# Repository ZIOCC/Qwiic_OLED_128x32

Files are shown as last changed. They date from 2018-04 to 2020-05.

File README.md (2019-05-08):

# Zio Qwiic OLED Display (0.91", 128x32 pixels)

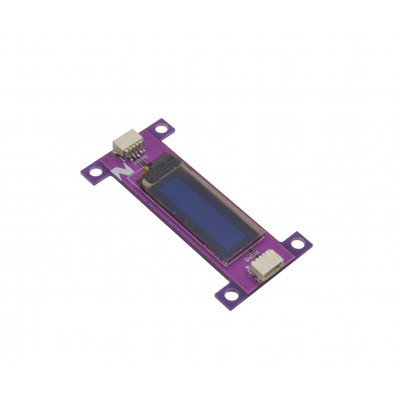
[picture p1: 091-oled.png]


> This product can be available for purchase [here](https://www.smart-prototyping.com/Zio-OLED-Display-0-91-in-128-32-Qwiic.html).

#### Description

This Zio OLED Display features a whopping 128x32 pixels in a small 0.91” (diagonal) frame. That’s 4,000 itsy-bitsy LEDs. [pause for effect]

Speed isn’t compromised however, thanks to its I2C command structure. Your firmware only needs to send the changes that it wants to make, rather than transferring information for every single pixel during each screen update.

As an OLED, it comes with all the perks of being able to emit light (unlike LCDs). No backlight layer here! Therefore, it’s thinner, consumes less power, and has higher contrast. With this size, it can display up to 3 lines of text.

The breakout board also features 4 mounting holes that can be snapped off and 2 Qwiic connectors to allow for quick and easy daisy-chaining.

> Note: As with all of the Version 1.0 Zio Qwiic boards, this board has been produced with the I2C pull-ups disconnected by default. If there's a significant length of wire between this board and your MCU, you'll need to solder closed the solder jumpers (labeled SDA, 3v3 and SCL) to connect the pull-up resistors to VCC.

#### Specification

* Communication Protocols: I2C
* IC: SSD1306
* I2C address: 0x3C
* Dimensions with Mounting  Tab: 25.1x 50.3mm
* Dimension without Mounting  Tab: 50.3x15.1mm
* Weight: 5g

#### Links

* [Adafruit GFX Library](https://github.com/adafruit/Adafruit-GFX-Library)
* [Adafruit SSD1306 Library](https://github.com/adafruit/Adafruit_SSD1306)
* [Demo Code](https://github.com/adafruit/Adafruit_SSD1306/tree/master/examples/ssd1306_128x32_i2c)
* [Eagle files](https://github.com/ZIOCC/Qwiic_OLED_128x32)

> ###### About Zio
> Zio is a new line of open sourced, compact, and grid layout boards, fully integrated for Arduino and Qwiic ecosystem. Designed ideally for wearables, robotics, small-space limitations or other on the go projects. Check out other awesome Zio products [here](https://www.smart-prototyping.com/Zio).

> All Zio products are released under the [Creative Commons Attribution, Share-Alike License](https://creativecommons.org/licenses/by-sa/4.0/), and in accordance with the principles of the [Open Source Hardware Association's OSHW Statement of Principles 1.0 and OSHW Definition 1.0](https://www.oshwa.org/definition/).

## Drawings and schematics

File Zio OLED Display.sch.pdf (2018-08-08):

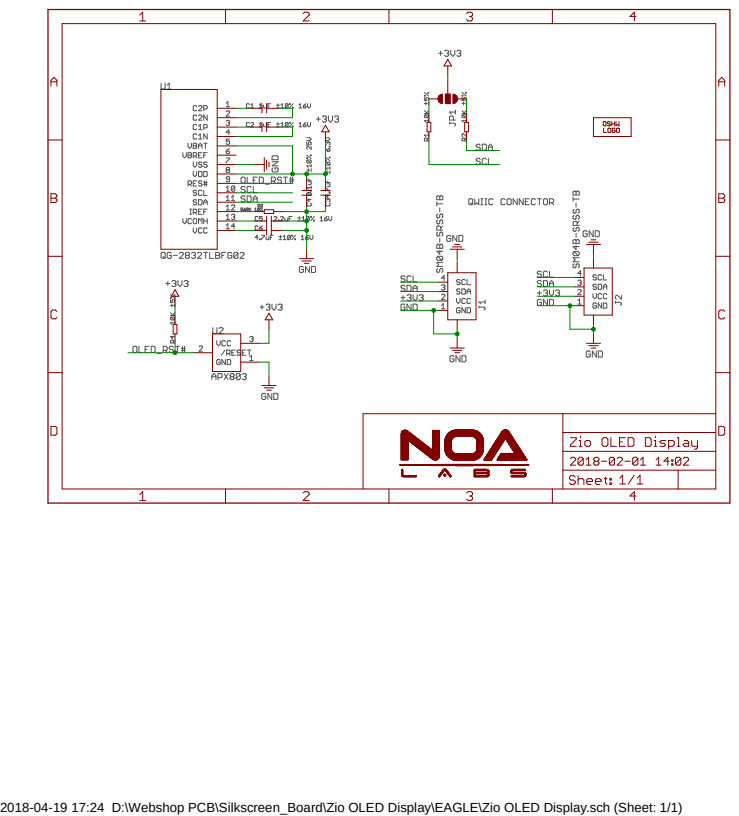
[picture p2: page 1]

2018-04-19 17:24 D:\Webshop PCB\Silkscreen_Board\Zio OLED Display\EAGLE\Zio OLED Display.sch (Sheet: 1/1)

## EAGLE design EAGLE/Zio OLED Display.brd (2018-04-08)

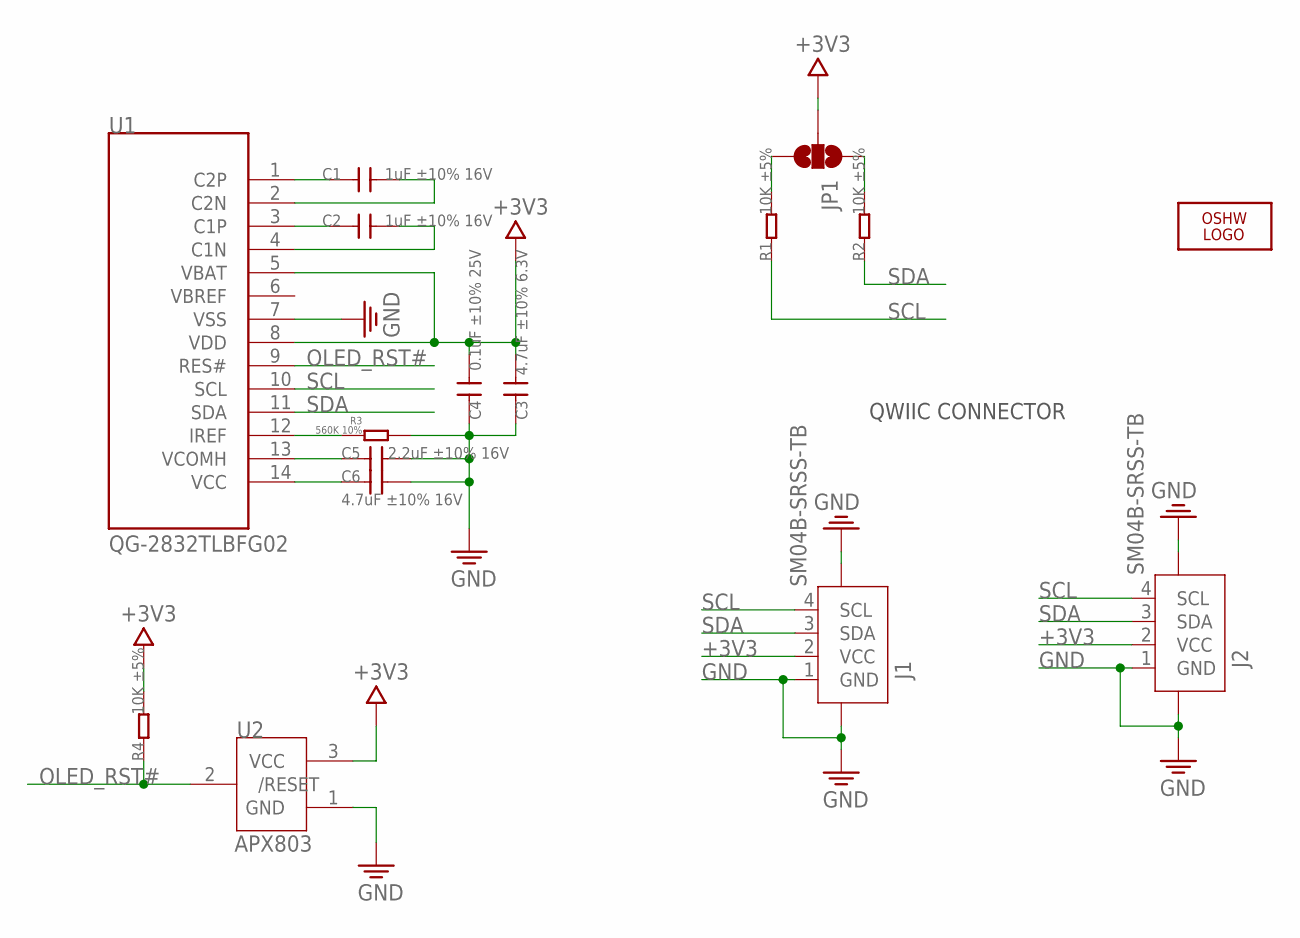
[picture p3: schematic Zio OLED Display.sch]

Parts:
C1, C2: 1uF ±10% 16V; 0603
C3: 4.7uF ±10% 6.3V; 0603
C4: 0.1uF ±10% 25V; 0603
C5: 2.2uF ±10% 16V; 0603
C6: 4.7uF ±10% 16V; 0603
J1, J2: SM04B-SRSS-TB; JST-SH-4P
JP1: JUMPER-SMT_3_2-NC_PASTE_NOCREM; SMT-JUMPER_3_2-NC_PASTE_SILK_NOCREM
LOGO1: LOGO-OSHW-6MILX0070-NT; OSHW_6X70_NOTEXT
R1, R2, R4: 10K ±5%; 0603
R3: 560K 10%; 0603
U1: QG-2832TLBFG02; OLED-12832
U2: APX803; SOT23

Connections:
+3V3: C3.1, C4.1, J1.2 (VCC), J2.2 (VCC), JP1.2, R4.2, U1.5 (VBAT), U1.8 (VDD), U2.3 (VCC)
GND: C3.2, C4.2, C5.2, C6.2, J1.1 (GND), J1.NC1 (5), J1.NC2 (6), J2.1 (GND), J2.NC1 (5), J2.NC2 (6), R3.1, U1.7 (VSS), U2.1 (GND)
unnamed: C1.2, U1.1 (C2P)
unnamed: C1.1, U1.2 (C2N)
unnamed: C2.2, U1.3 (C1P)
unnamed: C2.1, U1.4 (C1N)
unnamed: JP1.3, R1.2
unnamed: C5.1, U1.13 (VCOMH)
unnamed: C6.1, U1.14 (VCC)
unnamed: JP1.1, R2.2
unnamed: R3.2, U1.12 (IREF)
OLED_RST#: R4.1, U1.9 (RES#), U2.2 (/RESET)
SCL: J1.4 (SCL), J2.4 (SCL), R1.1, U1.10 (SCL)
SDA: J1.3 (SDA), J2.3 (SDA), R2.1, U1.11 (SDA)

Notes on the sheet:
QWIIC CONNECTOR

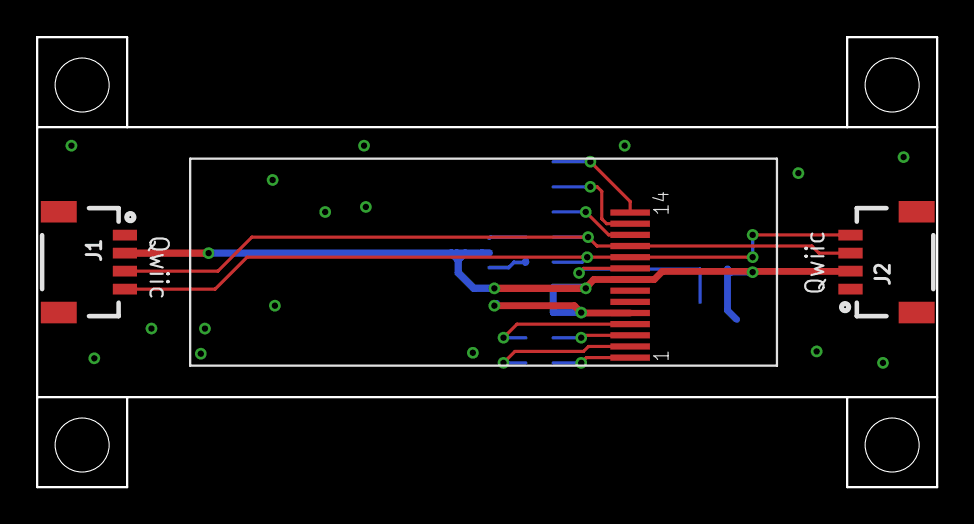
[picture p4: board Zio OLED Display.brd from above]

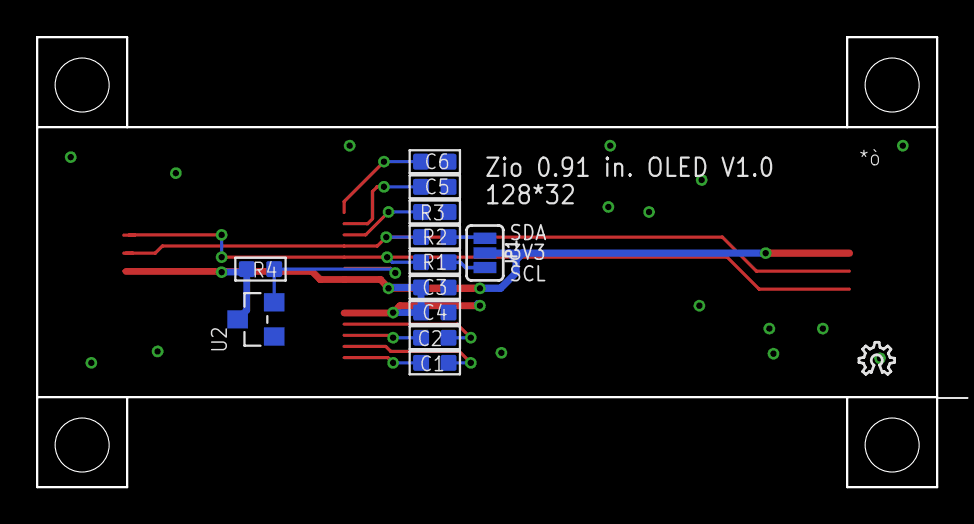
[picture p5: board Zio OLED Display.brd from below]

Board: 2 copper layers, 50.0 x 25.0 mm, 18 parts (14 on the bottom side), 14 nets.

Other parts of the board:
E$10: 7MM
U$3: 6MM

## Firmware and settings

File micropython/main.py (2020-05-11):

import sht31
from machine import Pin,I2C
from ssd1306 import SSD1306_I2C

i2c = I2C(sda=Pin("Y8"), scl=Pin("Y6"))
oled = SSD1306_I2C(128, 64, i2c, addr=0x3c)

sht = sht31.SHT31(i2c_address=0x44)
rtc = pyb.RTC()


while True:

    shtdata = sht.measure()
    t=rtc.datetime()
    oled.fill(0)
    oled.text("temp:" + str(shtdata[0]), 0, 10)
    oled.text("Humi:" + str(shtdata[1]), 0, 30)
    oled.text("Time:" + str(t[4]) + ":" + str(t[5]) + ":" + str(t[6]), 0, 45)
    print(str(t[6]))
    print(shtdata[0])
    print(shtdata[1])
    oled.show()
    pyb.delay(300)

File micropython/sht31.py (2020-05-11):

from machine import I2C, Pin
import time

# This is an updated library from the SHT30 libirary, we modified the address Pins to str instead of int
# so it can support different pyboard I2C ports
__version__ = '0.2.3'
__author__ = 'Roberto Sánchez'
__license__ = "Apache License 2.0. https://www.apache.org/licenses/LICENSE-2.0"

# Zio QWiic SHT31's default I2C address is 0x44
DEFAULT_I2C_ADDRESS = 0x44


class SHT31:
    """
    SHT30 sensor driver in pure python based on I2C bus

    References:
    * https://www.sensirion.com/fileadmin/user_upload/customers/sensirion/Dokumente/2_Humidity_Sensors/Sensirion_Humidity_Sensors_SHT3x_Datasheet_digital.pdf  # NOQA
    * https://www.wemos.cc/sites/default/files/2016-11/SHT30-DIS_datasheet.pdf
    * https://github.com/wemos/WEMOS_SHT3x_Arduino_Library
    * https://www.sensirion.com/fileadmin/user_upload/customers/sensirion/Dokumente/11_Sample_Codes_Software/Humidity_Sensors/Sensirion_Humidity_Sensors_SHT3x_Sample_Code_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
    """
    POLYNOMIAL = 0x131  # P(x) = x^8 + x^5 + x^4 + 1 = 100110001

    ALERT_PENDING_MASK = 0x8000     # 15
    HEATER_MASK = 0x2000            # 13
    RH_ALERT_MASK = 0x0800          # 11
    T_ALERT_MASK = 0x0400           # 10
    RESET_MASK = 0x0010             # 4
    CMD_STATUS_MASK = 0x0002        # 1
    WRITE_STATUS_MASK = 0x0001      # 0

    # MSB = 0x2C LSB = 0x06 Repeatability = High, Clock stretching = enabled
    MEASURE_CMD = b'\x2C\x10'
    STATUS_CMD = b'\xF3\x2D'
    RESET_CMD = b'\x30\xA2'
    CLEAR_STATUS_CMD = b'\x30\x41'
    ENABLE_HEATER_CMD = b'\x30\x6D'
    DISABLE_HEATER_CMD = b'\x30\x66'

    def __init__(self, scl_pin="Y9", sda_pin="Y10", delta_temp=0, delta_hum=0, i2c_address=DEFAULT_I2C_ADDRESS):
        self.i2c = I2C(scl=Pin(scl_pin), sda=Pin(sda_pin))
        self.i2c_addr = i2c_address
        self.set_delta(delta_temp, delta_hum)
        time.sleep_ms(50)

    def init(self, scl_pin="Y9", sda_pin="Y10"):
        """
        Init the I2C bus using the new pin values
        """
        self.i2c.init(scl=Pin(scl_pin), sda=Pin(sda_pin))

    def is_present(self):
        """
        Return true if the sensor is correctly conneced, False otherwise
        """
        return self.i2c_addr in self.i2c.scan()

    def set_delta(self, delta_temp=0, delta_hum=0):
        """
        Apply a delta value on the future measurements of temperature and/or humidity
        The units are Celsius for temperature and percent for humidity (can be negative values)
        """
        self.delta_temp = delta_temp
        self.delta_hum = delta_hum

    def _check_crc(self, data):
        # calculates 8-Bit checksum with given polynomial
        crc = 0xFF

        for b in data[:-1]:
            crc ^= b
            for _ in range(8, 0, -1):
                if crc & 0x80:
                    crc = (crc << 1) ^ SHT31.POLYNOMIAL
                else:
                    crc <<= 1
        crc_to_check = data[-1]
        return crc_to_check == crc

    def send_cmd(self, cmd_request, response_size=6, read_delay_ms=100):
        """
        Send a command to the sensor and read (optionally) the response
        The responsed data is validated by CRC
        """
        try:
            self.i2c.start()
            self.i2c.writeto(self.i2c_addr, cmd_request)
            if not response_size:
                self.i2c.stop()
                return
            time.sleep_ms(read_delay_ms)
            data = self.i2c.readfrom(self.i2c_addr, response_size)
            self.i2c.stop()
            for i in range(response_size//3):
                if not self._check_crc(data[i*3:(i+1)*3]):  # pos 2 and 5 are CRC
                    raise SHT31Error(SHT31Error.CRC_ERROR)
            if data == bytearray(response_size):
                raise SHT31Error(SHT31Error.DATA_ERROR)
            return data
        except OSError as ex:
            if 'I2C' in ex.args[0]:
                raise SHT31Error(SHT31Error.BUS_ERROR)
            raise ex

    def clear_status(self):
        """
        Clear the status register
        """
        return self.send_cmd(SHT31.CLEAR_STATUS_CMD, None)

    def reset(self):
        """
        Send a soft-reset to the sensor
        """
        return self.send_cmd(SHT31.RESET_CMD, None)

    def status(self, raw=False):
        """
        Get the sensor status register.
        It returns a int value or the bytearray(3) if raw==True
        """
        data = self.send_cmd(SHT31.STATUS_CMD, 3, read_delay_ms=20)

        if raw:
            return data

        status_register = data[0] << 8 | data[1]
        return status_register

    def measure(self, raw=False):
        """
        If raw==True returns a bytearrya(6) with sensor direct measurement otherwise
        It gets the temperature (T) and humidity (RH) measurement and return them.

        The units are Celsius and percent
        """
        data = self.send_cmd(SHT31.MEASURE_CMD, 6)

        if raw:
            return data

        t_celsius = (((data[0] << 8 |  data[1]) * 175) / 0xFFFF) - 45 + self.delta_temp
        rh = (((data[3] << 8 | data[4]) * 100.0) / 0xFFFF) + self.delta_hum
        return t_celsius, rh

    def measure_int(self, raw=False):
        """
        Get the temperature (T) and humidity (RH) measurement using integers.
        If raw==True returns a bytearrya(6) with sensor direct measurement otherwise
        It returns a tuple with 4 values: T integer, T decimal, H integer, H decimal
        For instance to return T=24.0512 and RH= 34.662 This method will return
        (24, 5, 34, 66) Only 2 decimal digits are returned, .05 becomes 5
        Delta values are not applied in this method
        The units are Celsius and percent.
        """
        data = self.send_cmd(SHT31.MEASURE_CMD, 6)
        if raw:
            return data
        aux = (data[0] << 8 | data[1]) * 175
        t_int = (aux // 0xffff) - 45
        t_dec = (aux % 0xffff * 100) // 0xffff
        aux = (data[3] << 8 | data[4]) * 100
        h_int = aux // 0xffff
        h_dec = (aux % 0xffff * 100) // 0xffff
        return t_int, t_dec, h_int, h_dec


class SHT31Error(Exception):
    """
    Custom exception for errors on sensor management
    """
    BUS_ERROR = 0x01
    DATA_ERROR = 0x02
    CRC_ERROR = 0x03

    def __init__(self, error_code=None):
        self.error_code = error_code
        super().__init__(self.get_message())

    def get_message(self):
        if self.error_code == SHT31Error.BUS_ERROR:
            return "Bus error"
        elif self.error_code == SHT31Error.DATA_ERROR:
            return "Data error"
        elif self.error_code == SHT31Error.CRC_ERROR:
            return "CRC error"
        else:
            return "Unknown error"
